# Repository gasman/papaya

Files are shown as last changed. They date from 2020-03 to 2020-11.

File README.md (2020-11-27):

# papAYa
an AY-3-8912 sound chip expansion board for the Raspberry Pi

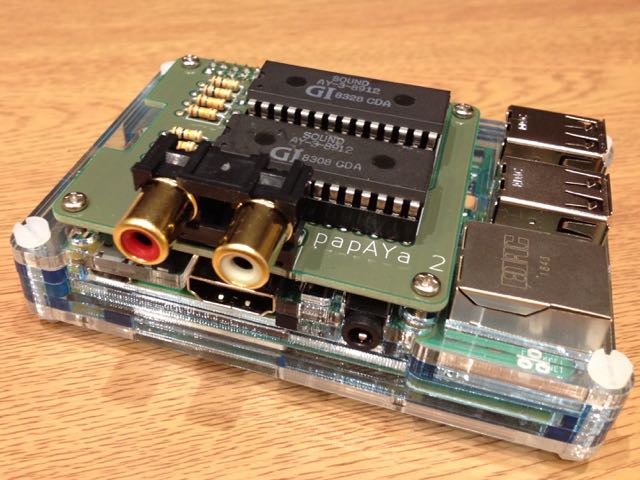
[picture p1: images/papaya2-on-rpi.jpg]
papAYa 2 board on a Raspberry Pi


## Why?
[I do ZX Spectrum chiptune performances](http://gasman.zxdemo.org/), but taking an entire ZX Spectrum setup to a venue is a faff, especially at gigs where the organisers are more used to people rocking up with a Gameboy, plugging in a jack and being ready to play. Some of the tracks I play require two sound chips, and taking two Spectrums would be even more of a faff.

Sure, you can emulate it, and honestly the AY is well-understood and deterministic enough that it would make no difference to the sound. But if you take that attitude, then what's the point of live music anyhow? I figure you don't need a 1980s-vintage Spectrum to be authentic, but you do at least need the actual sound chip.

Basically, I want to be as cool as the Gameboy folks. I want to get up on stage and make magic happen from a handheld device like I'm piloting a goddamn spaceship. And the best way to do that is to hook up an AY chip (or two) to a Raspberry Pi.

## What's here

* `papaya/` - KiCad files for the single-AY board
* `papaya2/` - KiCad files for the double-AY board
* `player/` - Command-line players for .psg files (as exported by [AY Emulator](https://bulba.untergrund.net/emulator_e.htm) and [Fuse](http://fuse-emulator.sourceforge.net/)). Requires [pigpio](http://abyz.me.uk/rpi/pigpio/) to build.
  * `player/psg` - plays a single-AY track in .psg format. Run with `sudo ./psg somefile.psg`
  * `player/psg2` - plays a dual-AY track exported as two .psg files. Run with `sudo ./psg2 somefile1.psg somefile2.psg`
* `server/` - Server software; see below
* `client/` - Client software to communicate with the papaya server
* `psgfiles/` - some example .psg files

## Bill of materials

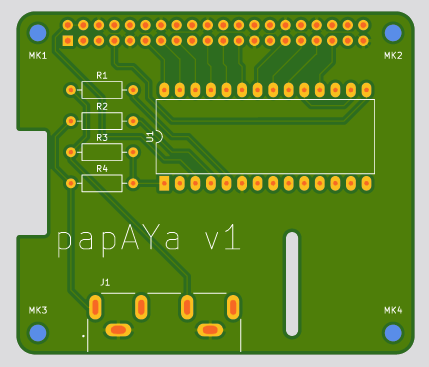
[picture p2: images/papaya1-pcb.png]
papAYa 1 PCB


For the single-AY board:
* Papaya v1 PCB
* P1 - 2x20 pin GPIO header https://www.adafruit.com/product/2222
* J1 - dual RCA connector [PJRAN2X1U01AUX](https://www.mouser.co.uk/ProductDetail/Switchcraft/PJRAN2X1U01AUX?qs=mcPJWgAPNre69iQqys4MXw%3D%3D)
* U1 - AY-3-8912 sound chip (_not_ AY-3-8912A - see below)
* R1, R2 - 10k resistor
* R3, R4 - 15k resistor

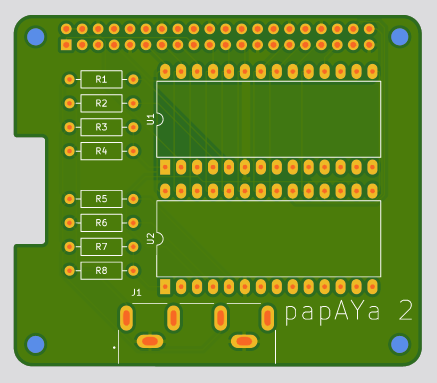
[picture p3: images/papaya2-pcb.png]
papAYa 2 PCB


For the dual-AY board:

* Papaya 2 PCB
* P1 - 2x20 pin GPIO header https://www.adafruit.com/product/2222
* J1 - dual RCA connector [PJRAN2X1U01AUX](https://www.mouser.co.uk/ProductDetail/Switchcraft/PJRAN2X1U01AUX?qs=mcPJWgAPNre69iQqys4MXw%3D%3D)
* U1, U2 - AY-3-8912 sound chip (_not_ AY-3-8912A - see below)
* R1, R2, R5, R6 - 10k resistor
* R3, R4, R7, R8 - 15k resistor

## Design considerations
The AY data bus (pins DA0-DA7) is connected directly to GPIO pins: 17, 27, 22, 10, 9, 11, 5, 6. The AY chip is a 5V device while the Raspberry Pi runs on 3.3V, but since the data direction is write-only and the AY accepts anything over 2.5V as logic high, no level conversion is needed.

For the first AY chip, BC1 is on GPIO pin 13 and BDIR is on pin 19. On the dual AY board, the second chip's BC1 is on pin 20 and BDIR is on pin 21. The clock signal is provided by the Raspberry Pi's hardware clock on GPIO pin 4. GPIO pin 26 is connected to RESET on both chips (NOTE: this is not implemented on the PCB yet).

Audio output is in ACB stereo format: channel A (of both chips) is mixed to the left, channel B to the right and C in the centre.

Some or all AY-3-8912A chips have a quirk where the RESET line must be toggled low then high in order to activate the noise generator - it does not function immediately on power-on. This is implemented in the software, but the PCB has not yet been updated to support this (the RESET line is held high instead) and so will currently only work with AY-3-8912 (not 8912A) chips.

Technically this board doesn't qualify as a HAT, as it doesn't include the identifying EPROM.

## Mounting
With socketed chips, the Raspberry Pi and papAYa combo fits neatly into a [SmartiPi Touch 2 case](https://thepihut.com/products/smartipi-touch-2) with a [15mm back cover](https://thepihut.com/products/smartipi-touch-2-back-cover), provided you use [11mm spacers](https://thepihut.com/products/raspberry-pi-hat-mounting-kit) rather than the slightly-taller ones that come with the touchscreen.

## Server
Rather than having each client program do its own low-level GPIO access (which typically requires running as root), the AY can be made available over a network service, running on TCP port 8912. See server/protocol.txt for details of the protocol.

To build, run `make` from the `server` directory - this requires [pigpio](http://abyz.me.uk/rpi/pigpio/). Copy the resulting `server` executable to `/usr/local/sbin/papaya`, and run it under supervisor using a configuration file such as (in `/etc/supervisor/conf.d/papaya.conf`):

    [program:papaya]
    command=/usr/local/sbin/papaya
    autostart=true
    autorestart=true

`client/psg.py` is a client program for playing .psg files, written in Python - run with:

    ./psg.py somefile.psg

Or, for multiple chips:

    ./psg.py somefile1.psg somefile2.psg

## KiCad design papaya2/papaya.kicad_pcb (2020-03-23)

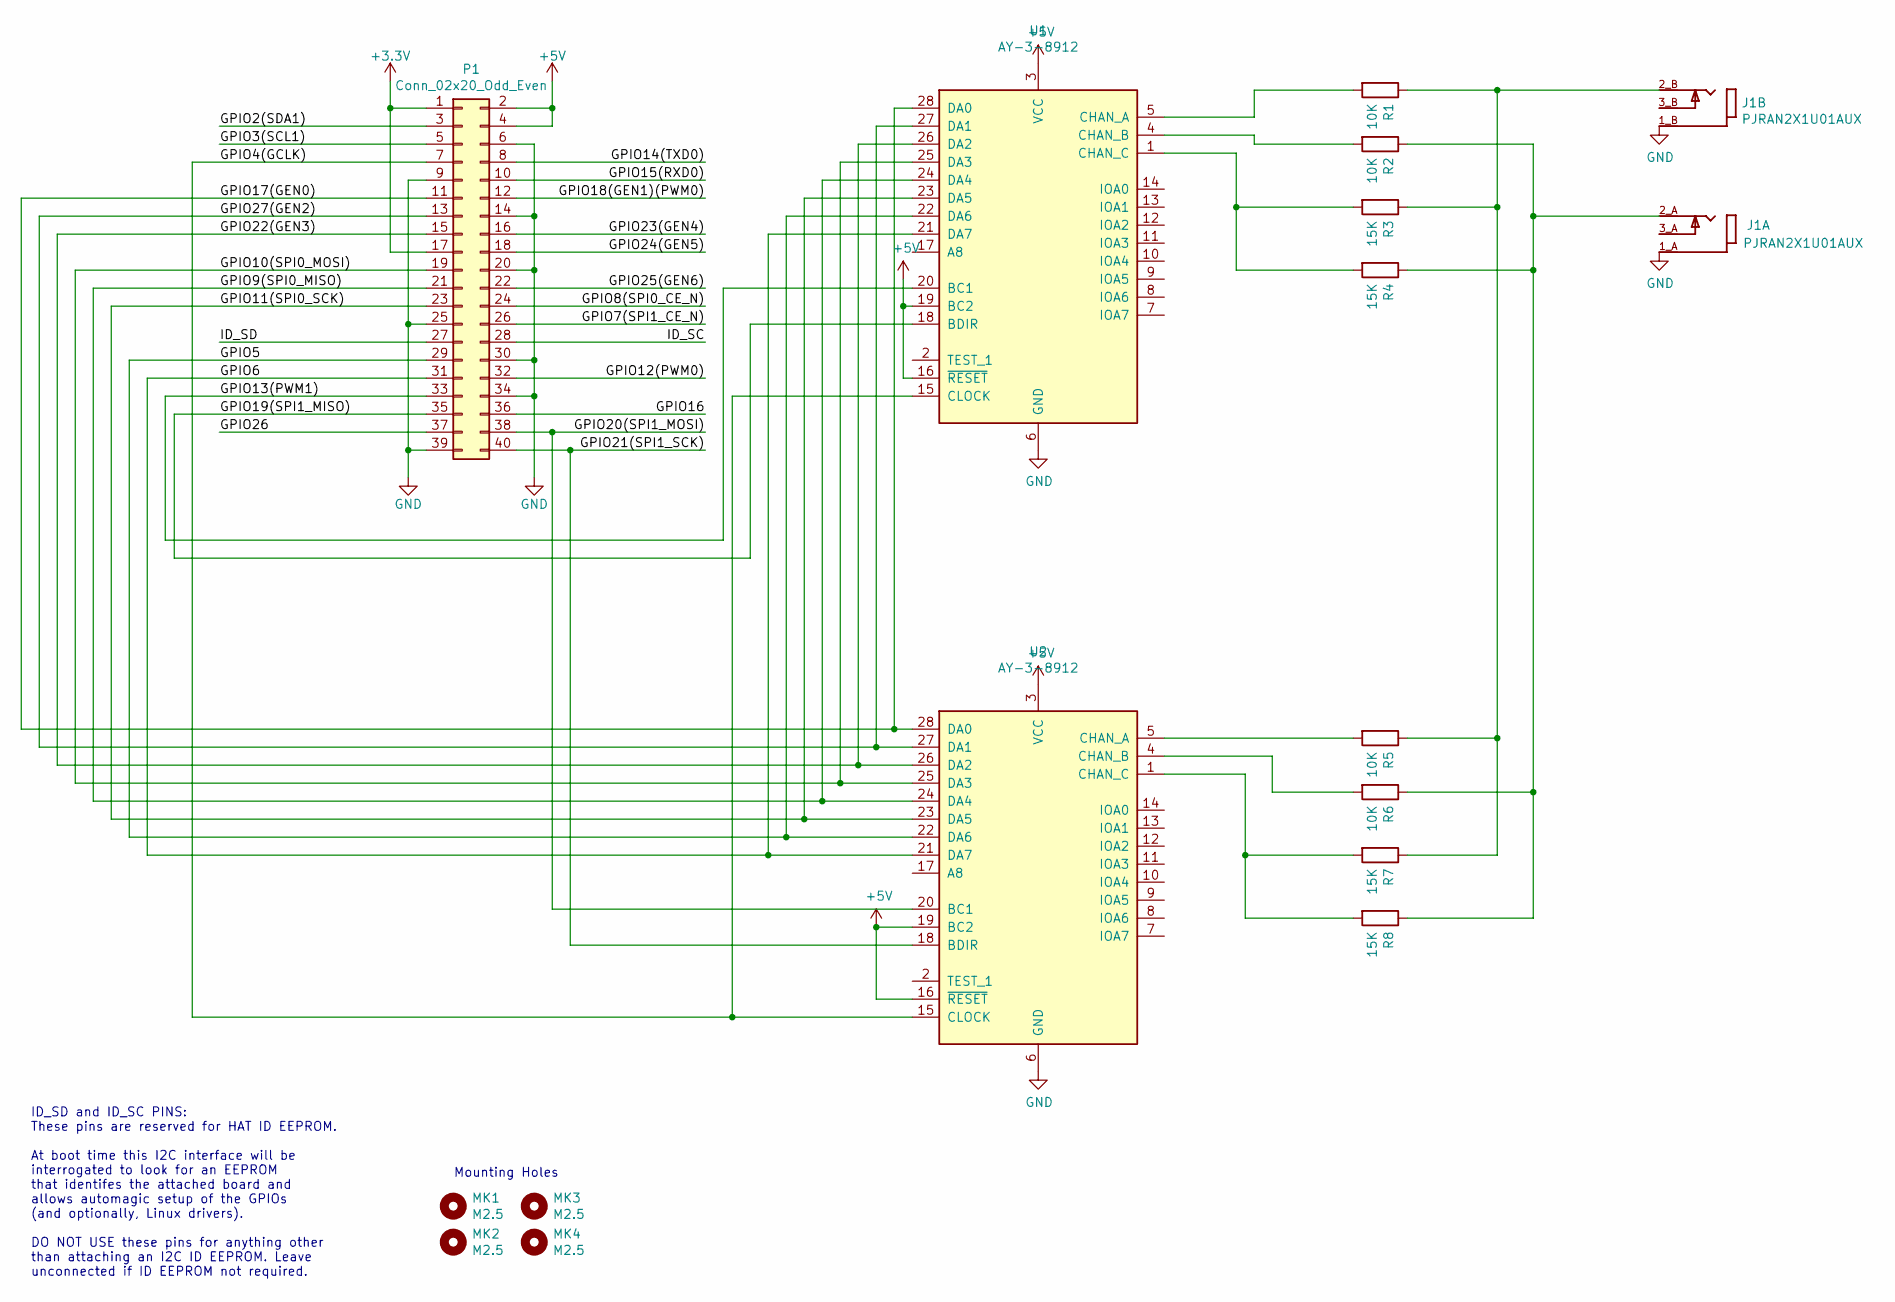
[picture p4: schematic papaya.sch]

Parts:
J1: PJRAN2X1U01AUX; SWITCHCRAFT_PJRAN2X1U01AUX
MK1, MK2, MK3, MK4: M2.5; MountingHole_2.7mm_M2.5
P1: Conn_02x20_Odd_Even; PinSocket_2x20_P2.54mm_Vertical
R1, R2, R5, R6: 10K; R_Axial_DIN0207_L6.3mm_D2.5mm_P10.16mm_Horizontal
R3, R4, R7, R8: 15K; R_Axial_DIN0207_L6.3mm_D2.5mm_P10.16mm_Horizontal
U1, U2: AY-3-8912; DIP-28_W15.24mm_LongPads

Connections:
+3V3: P1.1, P1.17
+5V: P1.2, P1.4, U1.3 (VCC), U1.16 (~RESET~), U1.19 (BC2), U2.3 (VCC), U2.16 (~RESET~), U2.19 (BC2)
/GPIO2(SDA1): P1.3
/GPIO3(SCL1): P1.5
/GPIO4(GCLK): P1.7, U1.15 (CLOCK), U2.15 (CLOCK)
/GPIO5: P1.29, U1.22 (DA6), U2.22 (DA6)
/GPIO6: P1.31, U1.21 (DA7), U2.21 (DA7)
/GPIO7(SPI1_CE_N): P1.26
/GPIO8(SPI0_CE_N): P1.24
/GPIO9(SPI0_MISO): P1.21, U1.24 (DA4), U2.24 (DA4)
/GPIO10(SPI0_MOSI): P1.19, U1.25 (DA3), U2.25 (DA3)
/GPIO11(SPI0_SCK): P1.23, U1.23 (DA5), U2.23 (DA5)
/GPIO12(PWM0): P1.32
/GPIO13(PWM1): P1.33, U1.20 (BC1)
/GPIO14(TXD0): P1.8
/GPIO15(RXD0): P1.10
/GPIO16: P1.36
/GPIO17(GEN0): P1.11, U1.28 (DA0), U2.28 (DA0)
/GPIO18(GEN1)(PWM0): P1.12
/GPIO19(SPI1_MISO): P1.35, U1.18 (BDIR)
/GPIO20(SPI1_MOSI): P1.38, U2.20 (BC1)
/GPIO21(SPI1_SCK): P1.40, U2.18 (BDIR)
/GPIO22(GEN3): P1.15, U1.26 (DA2), U2.26 (DA2)
/GPIO23(GEN4): P1.16
/GPIO24(GEN5): P1.18
/GPIO25(GEN6): P1.22
/GPIO26: P1.37
/GPIO27(GEN2): P1.13, U1.27 (DA1), U2.27 (DA1)
/ID_SC: P1.28
/ID_SD: P1.27
GND: J1.1_A (SLEEVE-A), J1.1_B (SLEEVE-B), P1.6, P1.9, P1.14, P1.20, P1.25, P1.30, P1.34, P1.39, U1.6 (GND), U2.6 (GND)
unnamed: J1.2_A (TIP-A), R2.1, R4.1, R6.1, R8.1
unnamed: J1.2_B (TIP-B), R1.1, R3.1, R5.1, R7.1
unnamed: R1.2, U1.5 (CHAN_A)
unnamed: R2.2, U1.4 (CHAN_B)
unnamed: R3.2, R4.2, U1.1 (CHAN_C)
unnamed: R5.2, U2.5 (CHAN_A)
unnamed: R6.2, U2.4 (CHAN_B)
unnamed: R7.2, R8.2, U2.1 (CHAN_C)

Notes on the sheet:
ID_SD and ID_SC PINS: These pins are reserved for HAT ID EEPROM. At boot time this I2C interface will be interrogated to look for an EEPROM that identifes the attached board and allows automagic setup of the GPIOs (and optionally, Linux drivers). DO NOT USE these pins for anything other than attach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
Mounting Holes

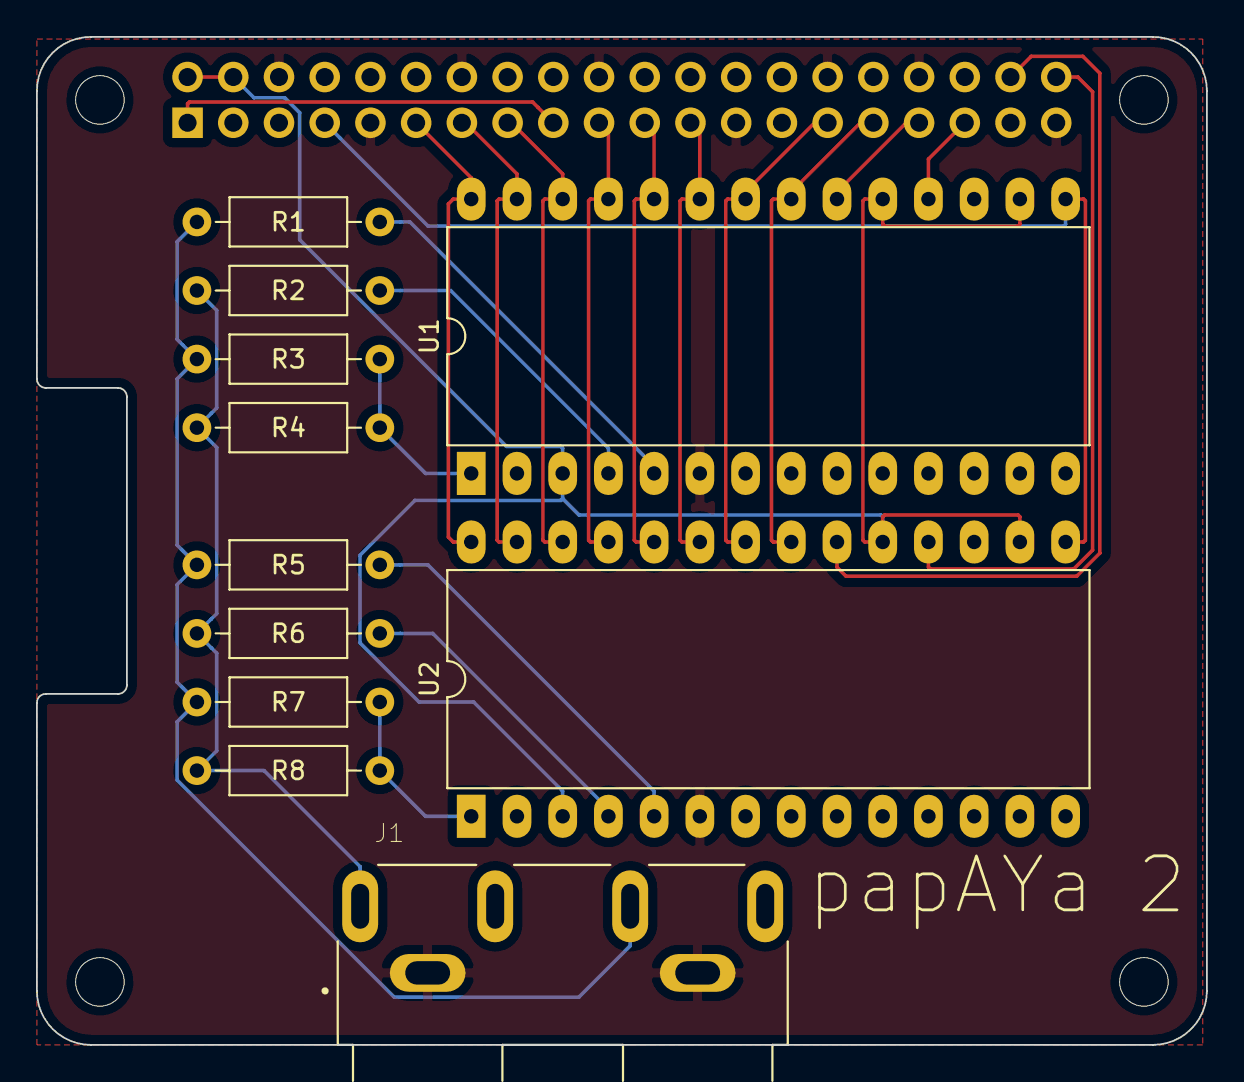
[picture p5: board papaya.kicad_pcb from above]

Board: 2 copper layers, 65.0 x 56.0 mm, 16 parts (1 on the bottom side), 24 nets.

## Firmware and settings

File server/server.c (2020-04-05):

#include <stdio.h>
#include <stdlib.h>
#include <sys/types.h>
#include <sys/socket.h>
#include <netinet/in.h>
#include <arpa/inet.h>
#include <unistd.h>
#include <errno.h>

#include <pigpio.h>

#include "ay.h"
#include "command_buffer.h"

#define PORT    8912

static int time_to_next_event;
static unsigned int current_timestamp, last_timestamp;
static int playing = 0;

void update_timer() {
    last_timestamp = current_timestamp;
    current_timestamp = gpioTick();
    time_to_next_event -= (current_timestamp - last_timestamp);
}


void sleep_until_next_event() {
    int busy_time = gpioTick() - current_timestamp;
    int wait_time = time_to_next_event - busy_time;
    if (wait_time > 0) gpioDelay(wait_time);
    update_timer();
}

void handle_command(unsigned char *command, int len) {
    unsigned int ay_freq;

    switch (command[0]) {
        case 'O': /* open */
            ay_freq = (command[2] << 24) | (command[3] << 16) | (command[4] << 8) | command[5];
            if (ay_init(ay_freq) < 0) {
                perror("AY initialisation");
                exit(EXIT_FAILURE);
            }
            current_timestamp = gpioTick();
            time_to_next_event = 0;
            cmdbuffer_clear();
            playing = 1;
            break;
        case 'S': /* stop immediately */
            ay_close();
            playing = 0;
            break;
        case 'R':
        case 'P':
        case 'C':
            cmdbuffer_write(command, len + 2);
            break;
        /* default:
            unknown command - read and discard */
    }
}


int main(int argc, char *argv[]) {
    int sock_fd, client_fd, cli_len, bytes_read, eof, busy, result;
    int enable = 1;
    struct sockaddr_in server_name, client_name;
    unsigned char incoming_command[257];
    unsigned char command_length;

    result = gpioInitialise();
    if (result < 0) {
        return result;
    }

    /* create the socket */
    sock_fd = socket(AF_INET, SOCK_STREAM, 0);
    if (sock_fd < 0) {
        perror("socket");
        exit(EXIT_FAILURE);
    }

    if (setsockopt(sock_fd, SOL_SOCKET, SO_REUSEADDR, &enable, sizeof(int)) < 0) {
        perror("setsockopt");
    }

    /* give the socket a name */
    server_name.sin_family = AF_INET;
    server_name.sin_port = htons(PORT);
    server_name.sin_addr.s_addr = htonl(INADDR_ANY);
    if (bind(sock_fd, (struct sockaddr *) &server_name, sizeof(server_name)) < 0) {
        perror("bind");
        exit(EXIT_FAILURE);
    }

    if (listen(sock_fd,0) < 0) {
        perror("listen");
        exit(EXIT_FAILURE);
    };

    while (1) {
        /* wait for connection */
        cli_len = sizeof(client_name);
        client_fd = accept(sock_fd, (struct sockaddr *) &client_name, &cli_len);
        if (client_fd < 0) {
            perror("accept");
            exit(EXIT_FAILURE);
        }

        /* write handshake message */
        if (send(client_fd, "beep boop\x00\x02", 11, 0) < 0) {
            perror("error writing to socket");
            exit(EXIT_FAILURE);
        }

        cmdbuffer_clear();
        playing = 0;
        eof = 0;

        while (!eof) {

            busy = 1;
            while (busy) {
                /* process outstanding commands from queue */
                while (playing && time_to_next_event <= 0 && !cmdbuffer_is_empty()) {
                    cmdbuffer_run(&time_to_next_event, &playing, client_fd);
                }

                if (cmdbuffer_is_full()) {
                    busy = 0;
                } else {
                    /* poll for new command, or block if queue is empty */
                    bytes_read = recv(
                        client_fd, incoming_command, 2,
                        cmdbuffer_is_empty() ? 0 : MSG_DONTWAIT
                    );
                    if (bytes_read < 0) {
                        if (errno == EWOULDBLOCK || errno == EAGAIN) {
                            busy = 0;
                        } else {
                            /* legitimate read error */
                            perror("recv");
                            exit(EXIT_FAILURE);
                        }
                    } else if (bytes_read < 2) {
                        eof = 1;
                        busy = 0;
                        if (playing) {
                            ay_close();
                            playing = 0;
                        }
                    } else {
                        /* read rest of command */
                        command_length = incoming_command[1];
                        if (command_length > 0) {
                            bytes_read = recv(client_fd, incoming_command + 2, command_length, 0);
                            if (bytes_read < command_length) {
                                eof = 1;
                                busy = 0;
                            } else {
                                handle_command(incoming_command, command_length);
                            }
                        } else {
                            handle_command(incoming_command, command_length);
                        }
                    }
                    if (playing) update_timer();
                }
            }

            if (playing && time_to_next_event > 0 && !eof) {
                sleep_until_next_event();
            }
        }

        if (shutdown(client_fd, SHUT_RDWR) < 0) {
            perror("shutdown");
            exit(EXIT_FAILURE);
        }
    }

    /* 
    close(sock_fd);
    return EXIT_SUCCESS;
    */
}

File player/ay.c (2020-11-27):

#include <pigpio.h>

static int pins[16] = {17, 27, 22, 10, 9, 11, 5, 6};
static int bc1_1 = 13;
static int bdir_1 = 19;
static int bc1_2 = 20;
static int bdir_2 = 21;
static int reset = 26;

static void setBus(int val) {
    int i;

    for (i=0; i<8; i++) {
        gpioWrite(pins[i], (val >> i) & 1);
    }
}

int ay_init(unsigned int ay_freq) {
    int i;

    for (i=0; i<8; i++) {
        gpioSetMode(pins[i], PI_OUTPUT);
    }
    gpioSetMode(bc1_1, PI_OUTPUT);
    gpioSetMode(bdir_1, PI_OUTPUT);
    gpioSetMode(bc1_2, PI_OUTPUT);
    gpioSetMode(bdir_2, PI_OUTPUT);
    gpioSetMode(reset, PI_OUTPUT);

    gpioHardwareClock(4, ay_freq);

    gpioWrite(reset, 0);
    gpioDelay(10);
    gpioWrite(reset, 1);

    return 0;
}

void ay_write(int reg, int val) {
    setBus(reg);
    gpioWrite_Bits_0_31_Set((1 << bc1_1) | (1 << bdir_1));
    gpioDelay(10);
    gpioWrite_Bits_0_31_Clear((1 << bc1_1) | (1 << bdir_1));

    setBus(val);
    gpioWrite(bdir_1, 1);
    gpioDelay(10);
    gpioWrite(bdir_1, 0);
}

void ay2_write(int reg, int val) {
    setBus(reg);
    gpioWrite_Bits_0_31_Set((1 << bc1_2) | (1 << bdir_2));
    gpioDelay(10);
    gpioWrite_Bits_0_31_Clear((1 << bc1_2) | (1 << bdir_2));

    setBus(val);
    gpioWrite(bdir_2, 1);
    gpioDelay(10);
    gpioWrite(bdir_2, 0);
}

void ay_silence() {
    int i;
    for (i=0; i < 14; i++) {
        ay_write(i, 0);
    }
}

void ay2_silence() {
    int i;
    for (i=0; i < 14; i++) {
        ay2_write(i, 0);
    }
}

void ay_close() {
    ay_silence();
    ay2_silence();
    gpioHardwareClock(4, 0);
}

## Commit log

2020-03-23 Add kicad files for papaya v1
    [papaya.kicad_pcb, papaya.sch]
2020-03-23 Add kicad files for papaya2
    [papaya.kicad_pcb, papaya.sch]
2020-04-05 First draft of the almighty Gasman concert control panel (also, variable framerate)
2020-11-27 Update ay.c to handle the reset line correctly
    [ay.c]
